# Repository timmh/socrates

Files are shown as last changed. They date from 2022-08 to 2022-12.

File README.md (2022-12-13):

# SOCRATES

Code and supplementary material for "SOCRATES: Introducing Depth in Visual Wildlife Monitoring using Stereo Vision" [[`Article`](https://doi.org/10.3390/s22239082)] [[`Data`](https://timm.haucke.xyz/datasets/plittersdorf)] [[`Website`](https://timm.haucke.xyz/publications/socrates)]

## Citation

If this is useful please consider citing:
```
@article{haucke2022socrates,
author = {Haucke, Timm and Kühl, Hjalmar S. and Steinhage, Volker},
title = {SOCRATES: Introducing Depth in Visual Wildlife Monitoring Using Stereo Vision},
journal = {Sensors},
volume = {22},
year = {2022},
number = {23},
article-number = {9082},
url = {https://www.mdpi.com/1424-8220/22/23/9082},
issn = {1424-8220},
doi = {10.3390/s22239082}
}
```

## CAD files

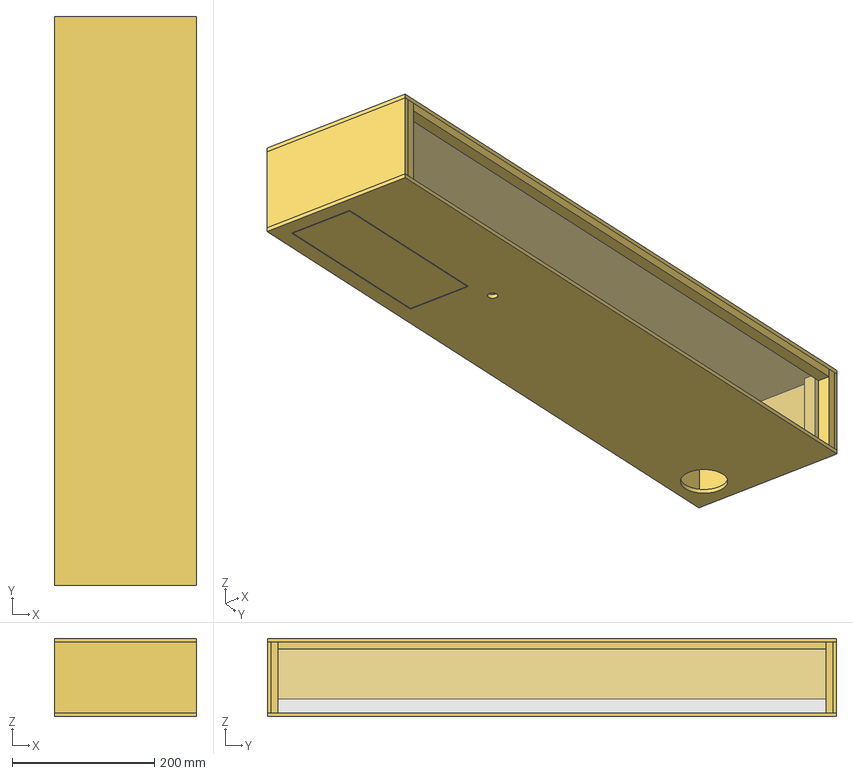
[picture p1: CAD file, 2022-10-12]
assembly/socrates_case.FCStd
200.0 x 800.0 x 110.0 mm
Roof
Glass
SideRight
SideLeft
Back
vbar1
vbar2
vbar3
vbar4
Rail
Floor
door
hbar

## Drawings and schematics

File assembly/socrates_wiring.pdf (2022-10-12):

## 5V Regulator

## PIR

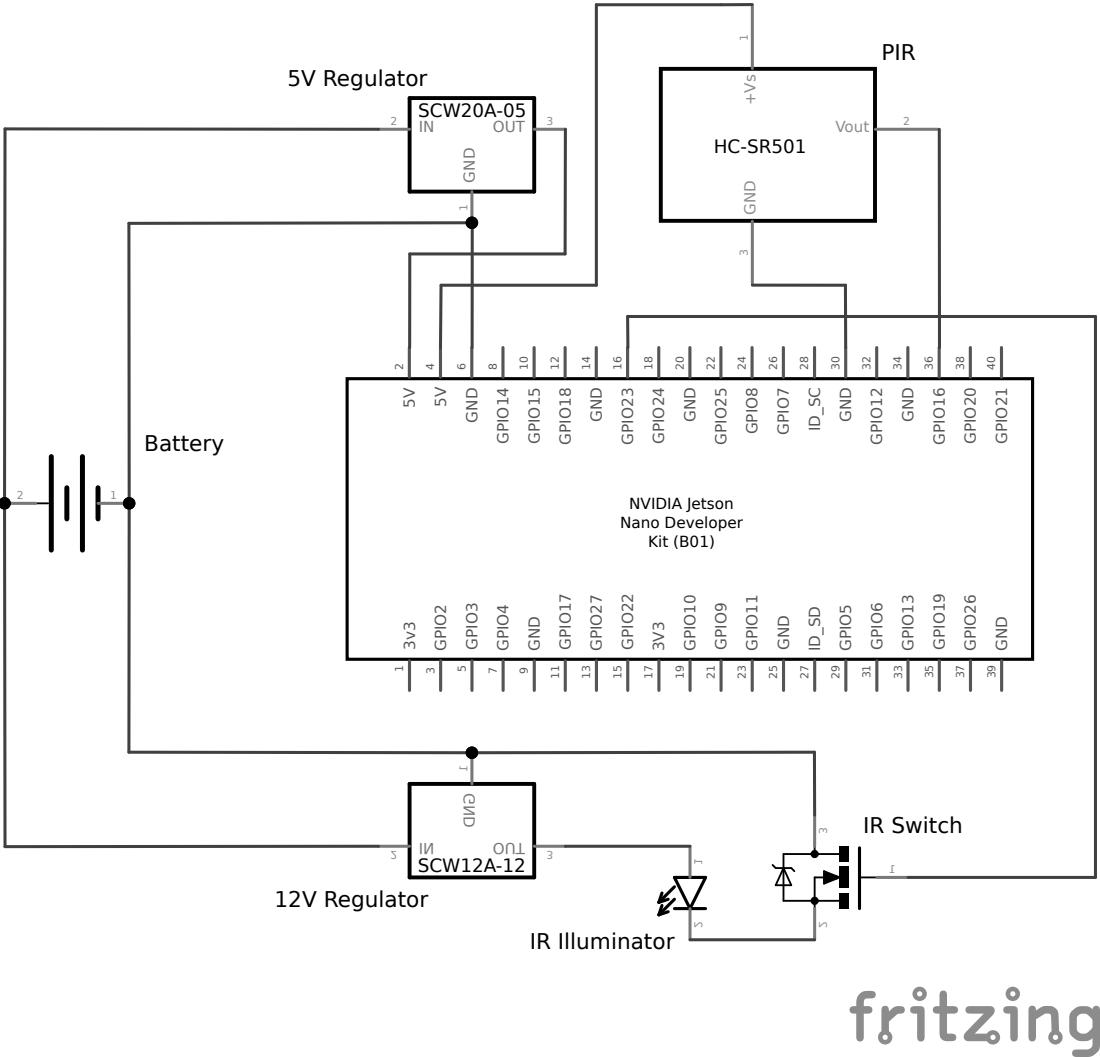
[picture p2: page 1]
NVIDIA Jetson Nano Developer Kit (B01); GPIO2 3 5V 4; GPIO3 5; GPIO4 7; GND 9; GPIO17; GPIO27; GPIO22; GPIO10; GPIO9; GPIO11; GND; GPIO5; GPIO6; GPIO13 33; GPIO19; GPIO26; GPIO14 8; GND 6; GPIO15; GPIO18; GPIO24; GPIO23; GPIO8; GPIO25; GPIO7; GPIO12; GPIO20; GPIO16; GPIO21; SCW12A-12; 1 GND; 3 OUT; SCW20A-05 2; 2 Vout; 3 GND 1 +Vs; Battery; 12V Regulator; IR Illuminator; IR Switch

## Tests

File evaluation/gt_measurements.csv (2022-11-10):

Object | Ground Truth [m]
right tub | 14.9
second near tree from right | 18.8
center right near tree | 22.4
center feeding trough | 37.5
center left near tree | 35.0
second narrow tree from left | 33.4

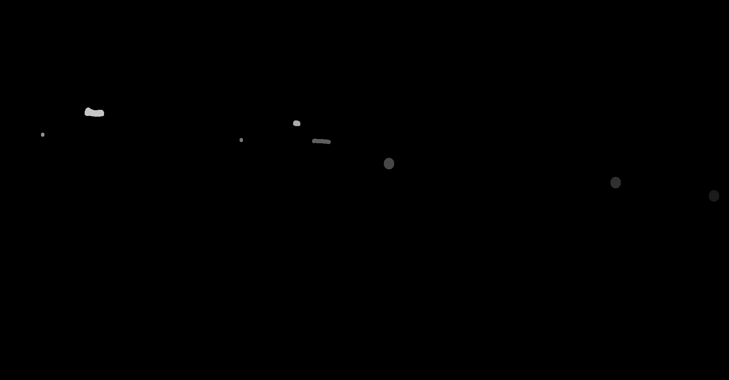
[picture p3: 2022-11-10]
evaluation/gt_measurements_mask.png

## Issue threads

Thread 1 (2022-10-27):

How to load precomputed depth?

mtangemann, 2022-10-27:
Hi Timm,

Thank you very much for your efforts to open source your dataset and codebase!

I am trying to load the precomputed depth in meters for the [labelled images](https://zenodo.org/record/7035934), but I'm not sure whether I do it correctly. The data doesn't seem do be depth directly, since the values don't fit at all (greater values for pixels closer to the camera):

```python
data = cv2.imread("images/20220209150523_000090.exr", cv2.IMREAD_ANYCOLOR | cv2.IMREAD_ANYDEPTH)

plt.matshow(data)
plt.colorbar()
```

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

So I am assuming that the data is disparity in pixels. Converting to depth using the parameters from [utils/prepare_distance_sampling.py](https://github.com/timmh/socrates/blob/main/utils/prepare_distance_sampling.py) looks more sensible, but a maximal distance of >200m seems to be quite far.

```python
camera_baseline = 0.25  # meters
camera_horizontal_pixels = 1920  # pixels
camera_horizontal_sensor_size = 0.007564  # meters
camera_disparity_to_depth_factor = camera_focal_length * camera_baseline * camera_horizontal_pixels * camera_horizontal_sensor_size ** -1

plt.matshow(camera_disparity_to_depth_factor / data)
plt.colorbar()
```

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

It would be super helpful if you could add a code snippet showing how to correctly load the precomputed depth data.

Thank you,
Matthias

timmh, 2022-11-04:
Hi Matthias,

you are correct, the EXR files contain disparity in pixels. I just re-checked the rectification, EXR extraction and the [parameters](https://github.com/timmh/socrates/blob/ef54f613fdb82e5047c94835779c0ecbfd1cb6d5/utils/prepare_distance_sampling.py) you used, and everything seems to be correct. I also just performed ground truth measurements using a laser rangefinder, which match the distances obtained using the parameters above. Note that the baseline for this experiment was just 25cm, so measurements at large distances are expected to have huge errors. The actual largest distance, at the fence in the top left of the image, is around 140m, according to my laser rangefinder.

Please let me know if this answers your question or if I can be of help. Best,
Timm

mtangemann, 2022-11-09:
Hi Timm,

Thank you for your reply and even doing ground truth measurements! My main concern was that I might use the data in the wrong way; this has been addressed so I'll close this issue.

Thank you,
Matthias

Closed 2022-11-09.

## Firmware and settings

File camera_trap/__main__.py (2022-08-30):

import sys
import logging
import asyncio
# from systemd.journal import JournalHandler
from .camera_trap import CameraTrap
from dotenv import load_dotenv


def main():
    assert sys.version_info >= (3, 6)
    load_dotenv()
    logging.basicConfig(
        handlers=[logging.FileHandler("log.txt"), logging.StreamHandler()],
        format="%(asctime)s %(levelname)-8s %(message)s",
        level=logging.INFO,
        datefmt="%Y%m%d%H%M%S",
    )
    camera_trap = CameraTrap()
    loop = asyncio.get_event_loop()
    try:
        loop.run_until_complete(camera_trap.loop())
    except KeyboardInterrupt:
        camera_trap.__del__()

if __name__ == "__main__":
    main()

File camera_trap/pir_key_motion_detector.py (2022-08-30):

import asyncio
import evdev
import time


class PirKeyMotionDetector:
    def __init__(self, keycode="KEY_POWER", detection_duration=30., cooldown_duration=5 * 60.):
        self.device = evdev.InputDevice("/dev/input/by-path/platform-gpio-keys-event")
        self.keycode = keycode
        self.detection_duration = detection_duration
        self.cooldown_duration = cooldown_duration
        self.last_detection_time = 0
        self.scheduled_wakeup_time = None

    def set_scheduled_wakeup_time(self, scheduled_wakeup_time):
        self.scheduled_wakeup_time = scheduled_wakeup_time

    async def motion_detected(self) -> bool:
        async for event in self.device.async_read_loop():
            if event.type == evdev.ecodes.EV_KEY:
                event = evdev.KeyEvent(event)
                if event.keystate == evdev.KeyEvent.key_up and event.keycode == self.keycode:
                    now = time.time()
                    if (self.last_detection_time + self.detection_duration + self.cooldown_duration < now) and (self.scheduled_wakeup_time is None or self.scheduled_wakeup_time > now):
                        self.last_detection_time = now
                        yield True
                        await asyncio.sleep(self.detection_duration)
                        yield False

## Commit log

2022-08-30 add utilities to rectify and sample frames from raw videos
2022-10-12 add 3D models
    [socrates_case.FCStd]
2022-10-12 add wiring diagrams
    [socrates_wiring.fzz]
2022-10-21 make currently unused deepmatching installation optional
2022-10-21 make currently unused COTR installation optional
2022-11-10 add disparity evaluation code and ground truth
    [gt_measurements.csv]
